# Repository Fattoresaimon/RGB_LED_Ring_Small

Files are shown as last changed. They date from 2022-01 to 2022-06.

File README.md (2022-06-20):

# RGB LED Ring Small
### This is the official repository of the RGB LED Ring Small!
### Available on my [DuPPa Store!](https://www.duppa.net/shop/rgb-led-ring-small/) or [Tindie](https://www.tindie.com/products/25812/)!

The RGB LED Ring Small is an accessory of the rotary encoder.
The shaft  of the encoder can be insert in the center hole of the board. It support both the normal rotary encoder and the RGB encoder.

There are 24 RGB LED disposed in a circle with a 30mm diameter. In total there are 72 LEDs.
Each single LED can be controller with 256 step, then each RGB LED are encoded with the 888 format.
The controller is the [ IS31FL3746](https://www.lumissil.com/assets/pdf/core/IS31FL3746A_DS.pdf)

In this repository you can find:
- [Schematic](/PDF/)
- [Gerbers](/Hardware/Gerber/)
- [BOM](/Hardware/BOM/)
- [Pick & Place](/Hardware/Pick%20Place/)
- [3D File](/Hardware/ExportSTEP/)

[Here you can find the Arduino library](https://github.com/Fattoresaimon/ArduinoDuPPaLib)

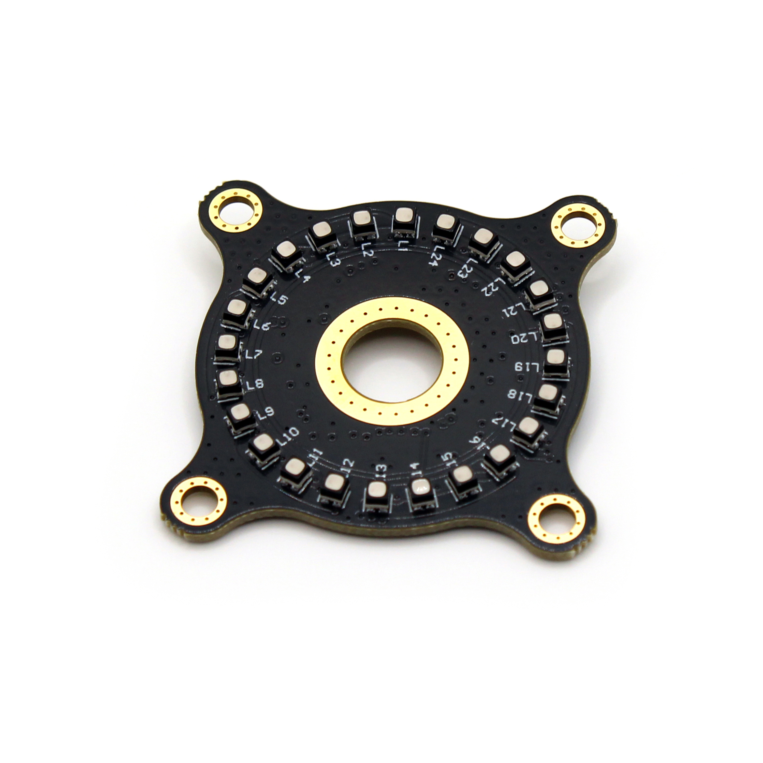
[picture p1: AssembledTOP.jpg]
Assembled


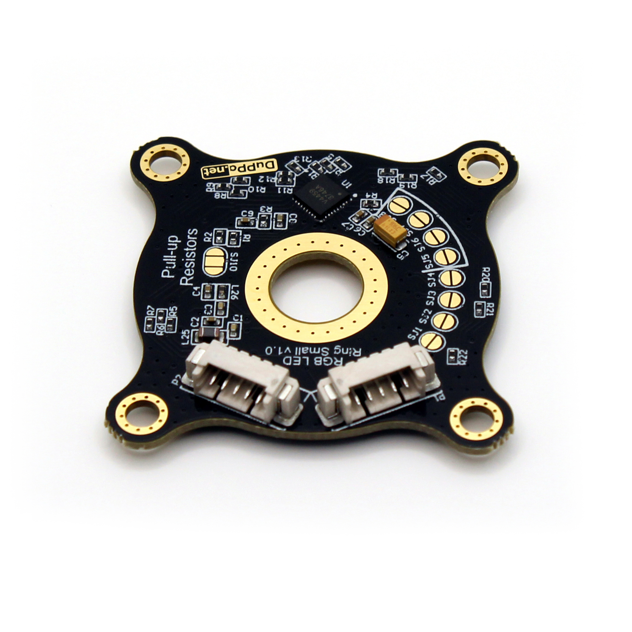
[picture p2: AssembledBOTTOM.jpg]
Bottom


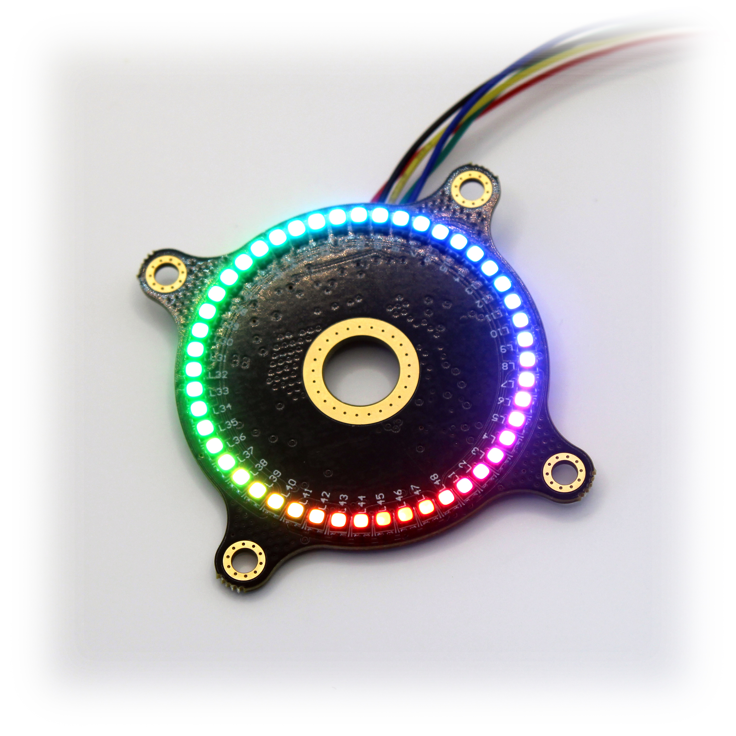
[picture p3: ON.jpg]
ON


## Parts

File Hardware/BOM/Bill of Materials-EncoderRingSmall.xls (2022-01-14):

Comment | Designator | Footprint | Quantity | Voltage | Value | PartNumber
C-EUC0402 | C1, C3 | C0402 | 2 | 16V | 10n | CL05B103KA5NNNC
C-EUC0402 | C2, C4, C7, C9 | C0402 | 4 | 16V | 100n | CL05B104KO5NNNC
Tantalum Case-A | C5 | SMC_A | 1 | 16V | 10u | CA45-A016K106T
C-EUC0402 | C6, C8 | C0402 | 2 | 16V | 470n | CL05A474KA5NNNC
RGB_2020_NH-Z1921RGBA-SG | L1, L2, L3, L4, L5, L6, L7, L8, L9, L10, L11, L12, L13, L14, L15, L16, L17, L18, L19, L20, L21, L22, L23, L24 | RGB_2121_NH-Z1921RGBA-SG | 24 |  |  | NH-Z1921RGBA-SG
600R@100MHz | L25 | L0805 | 1 |  |  | CBW201209U601T
600R@100MHz | L26 | L0402 | 1 |  |  | CBG100505U601T
Header 5HSMD | P1, P2 | MOLX-52361-0571-5_V | 2 |  |  | C22076
R-EU_R0402 | R1, R2, R3 | R0402 | 3 |  | 4k7 | 0402WGJ0472TCE
R-EU_R0402 | R4 | R0402 | 1 |  | 10k | RC-02W1002FT
R-EU_R0402 | R5, R8, R11, R14, R17, R20 | R0402 | 6 |  | 51r | RC0402JR-0751RL
R-EU_R0402 | R6, R7, R9, R10, R12, R13, R15, R16, R18, R19, R21, R22 | R0402 | 12 |  | 20r | RC0402JR-0720RL
IS31FL3746A | U1 | PQFN40P400X400X75_HS-33N | 1 |  |  | IS31FL3746A

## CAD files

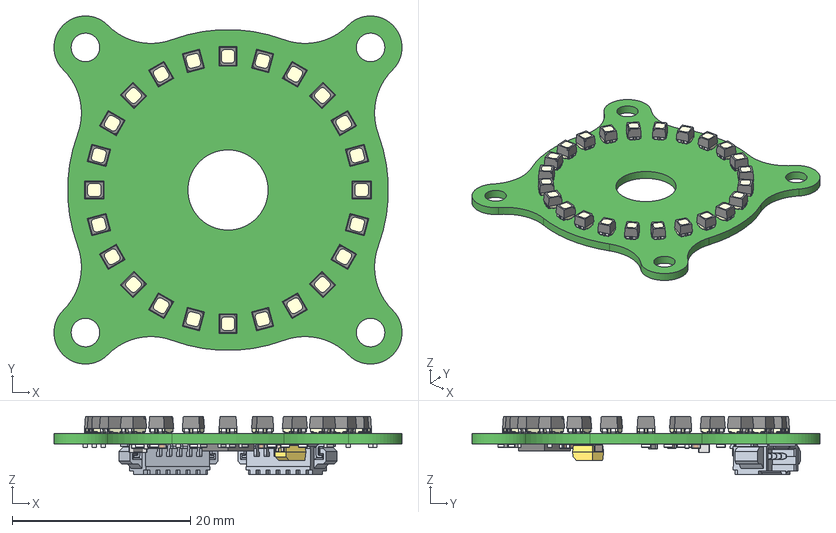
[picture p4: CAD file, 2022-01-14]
Hardware/ExportSTEP/EncoderRingSmall.step
39.1 x 39.1 x 6.51 mm
User_Library-R_0402 x 22
ASMB-KTF0-0A306--3DModel-STEP-56544 x 24
User_Library-V0402HD_K_X_F6rper_1
User_Library-V0402HD_Anschl_X_FCsse_1
User_Library-ind_0805
User_Library-Capacitor_0402 x 8
Open_CASCADE_STEP_translator_6.8_19.1
Open_CASCADE_STEP_translator_6.8_19.2.1
Thermal_Shape
Pin_Shape x 32

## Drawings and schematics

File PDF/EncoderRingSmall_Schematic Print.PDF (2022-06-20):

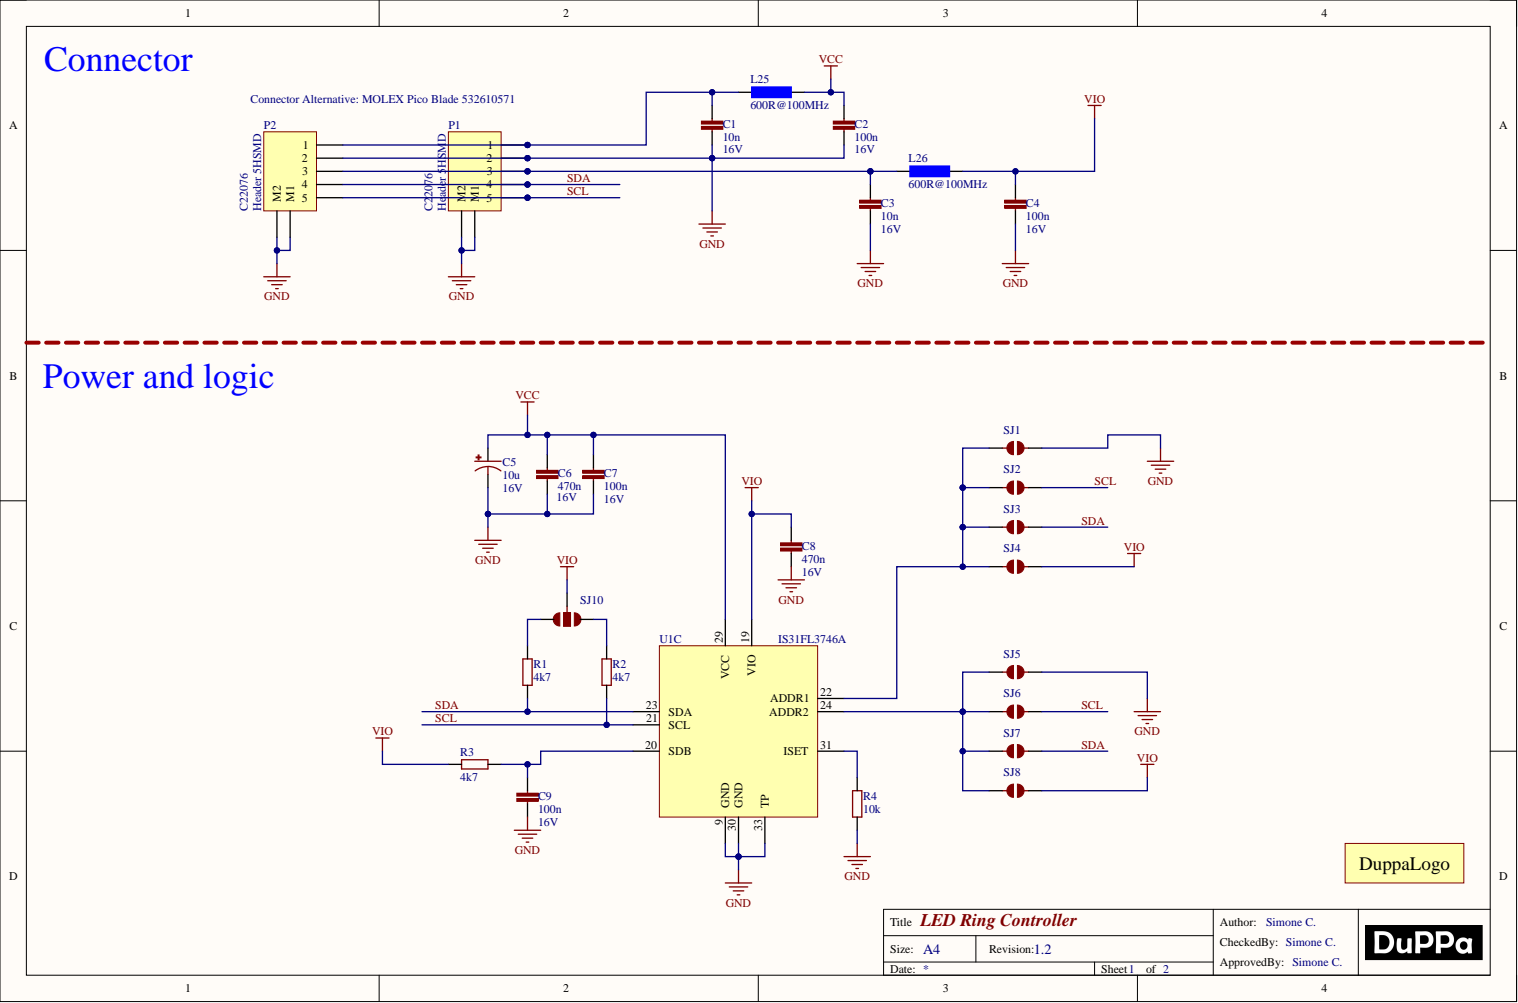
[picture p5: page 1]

Connector Alternative: MOLEX Pico Blade 532610571

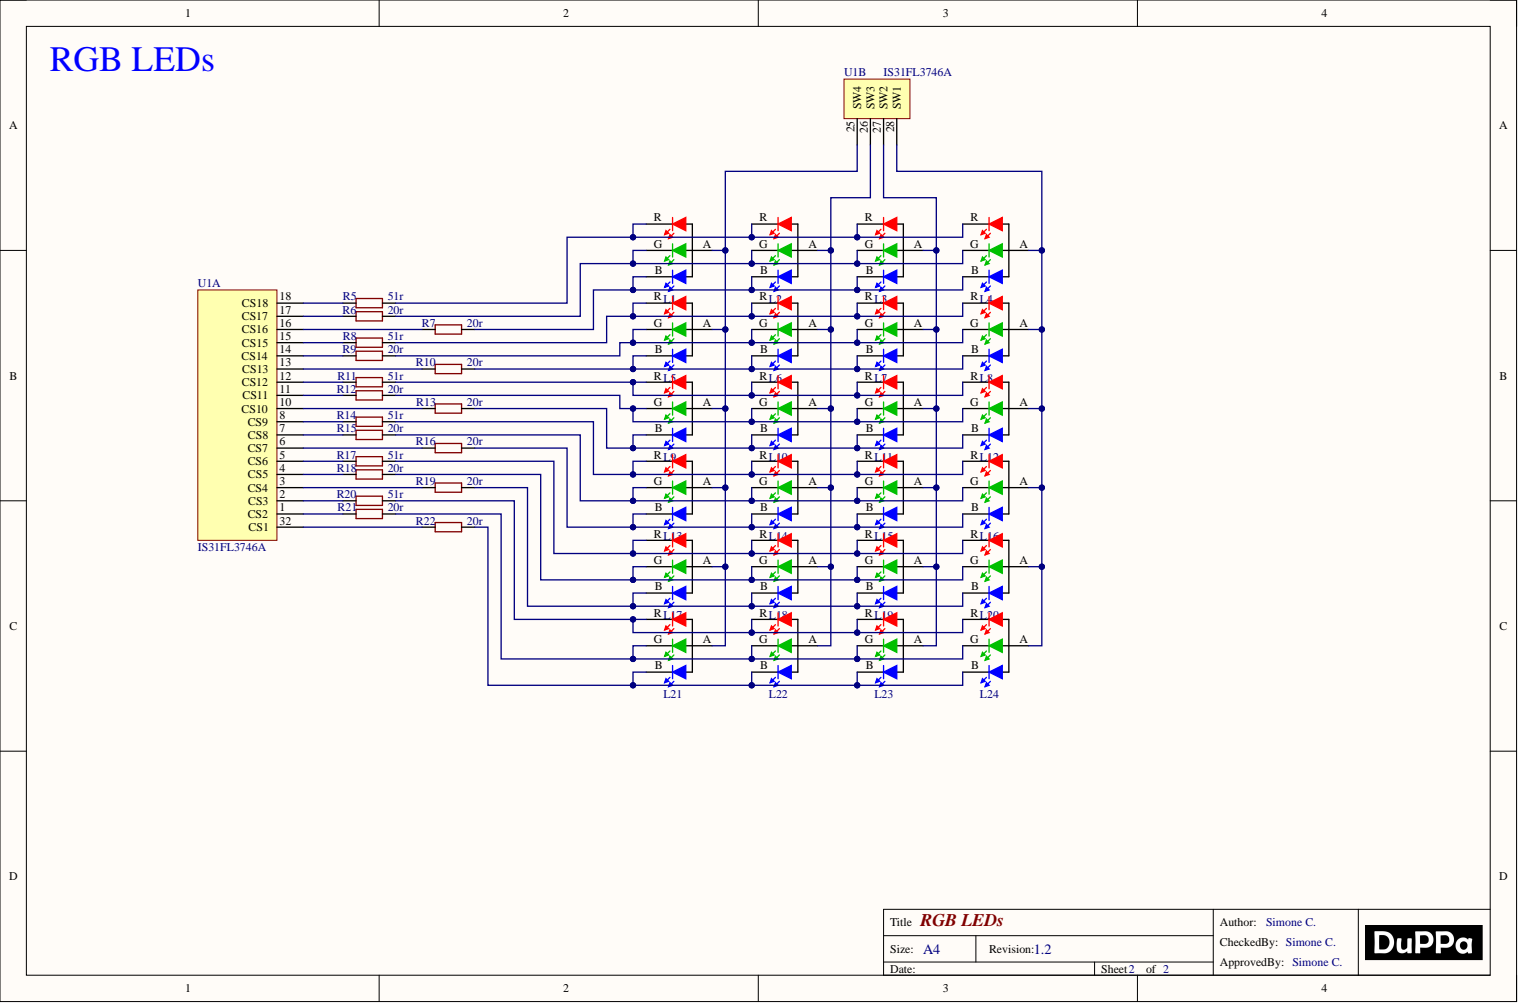
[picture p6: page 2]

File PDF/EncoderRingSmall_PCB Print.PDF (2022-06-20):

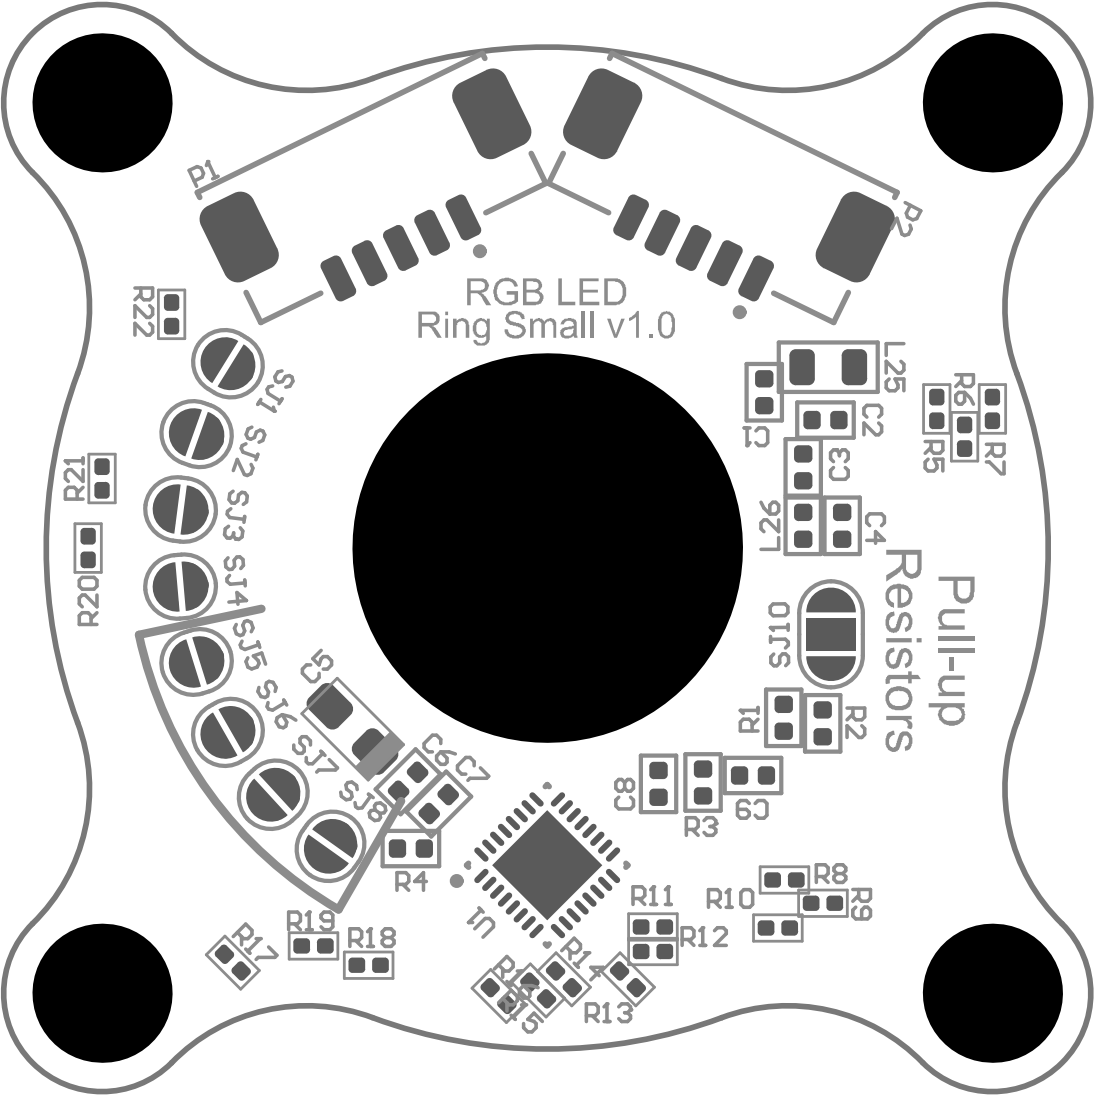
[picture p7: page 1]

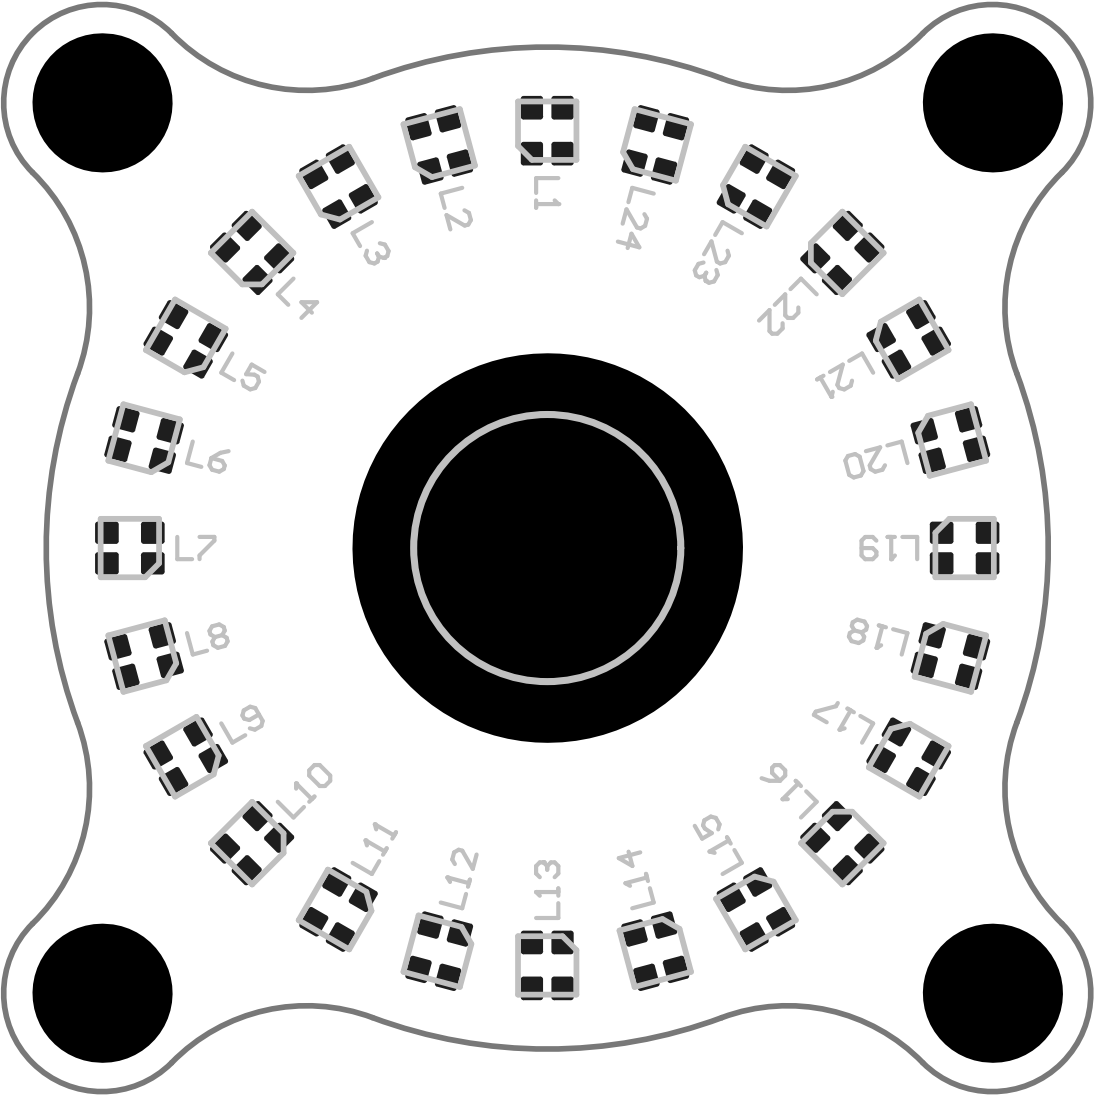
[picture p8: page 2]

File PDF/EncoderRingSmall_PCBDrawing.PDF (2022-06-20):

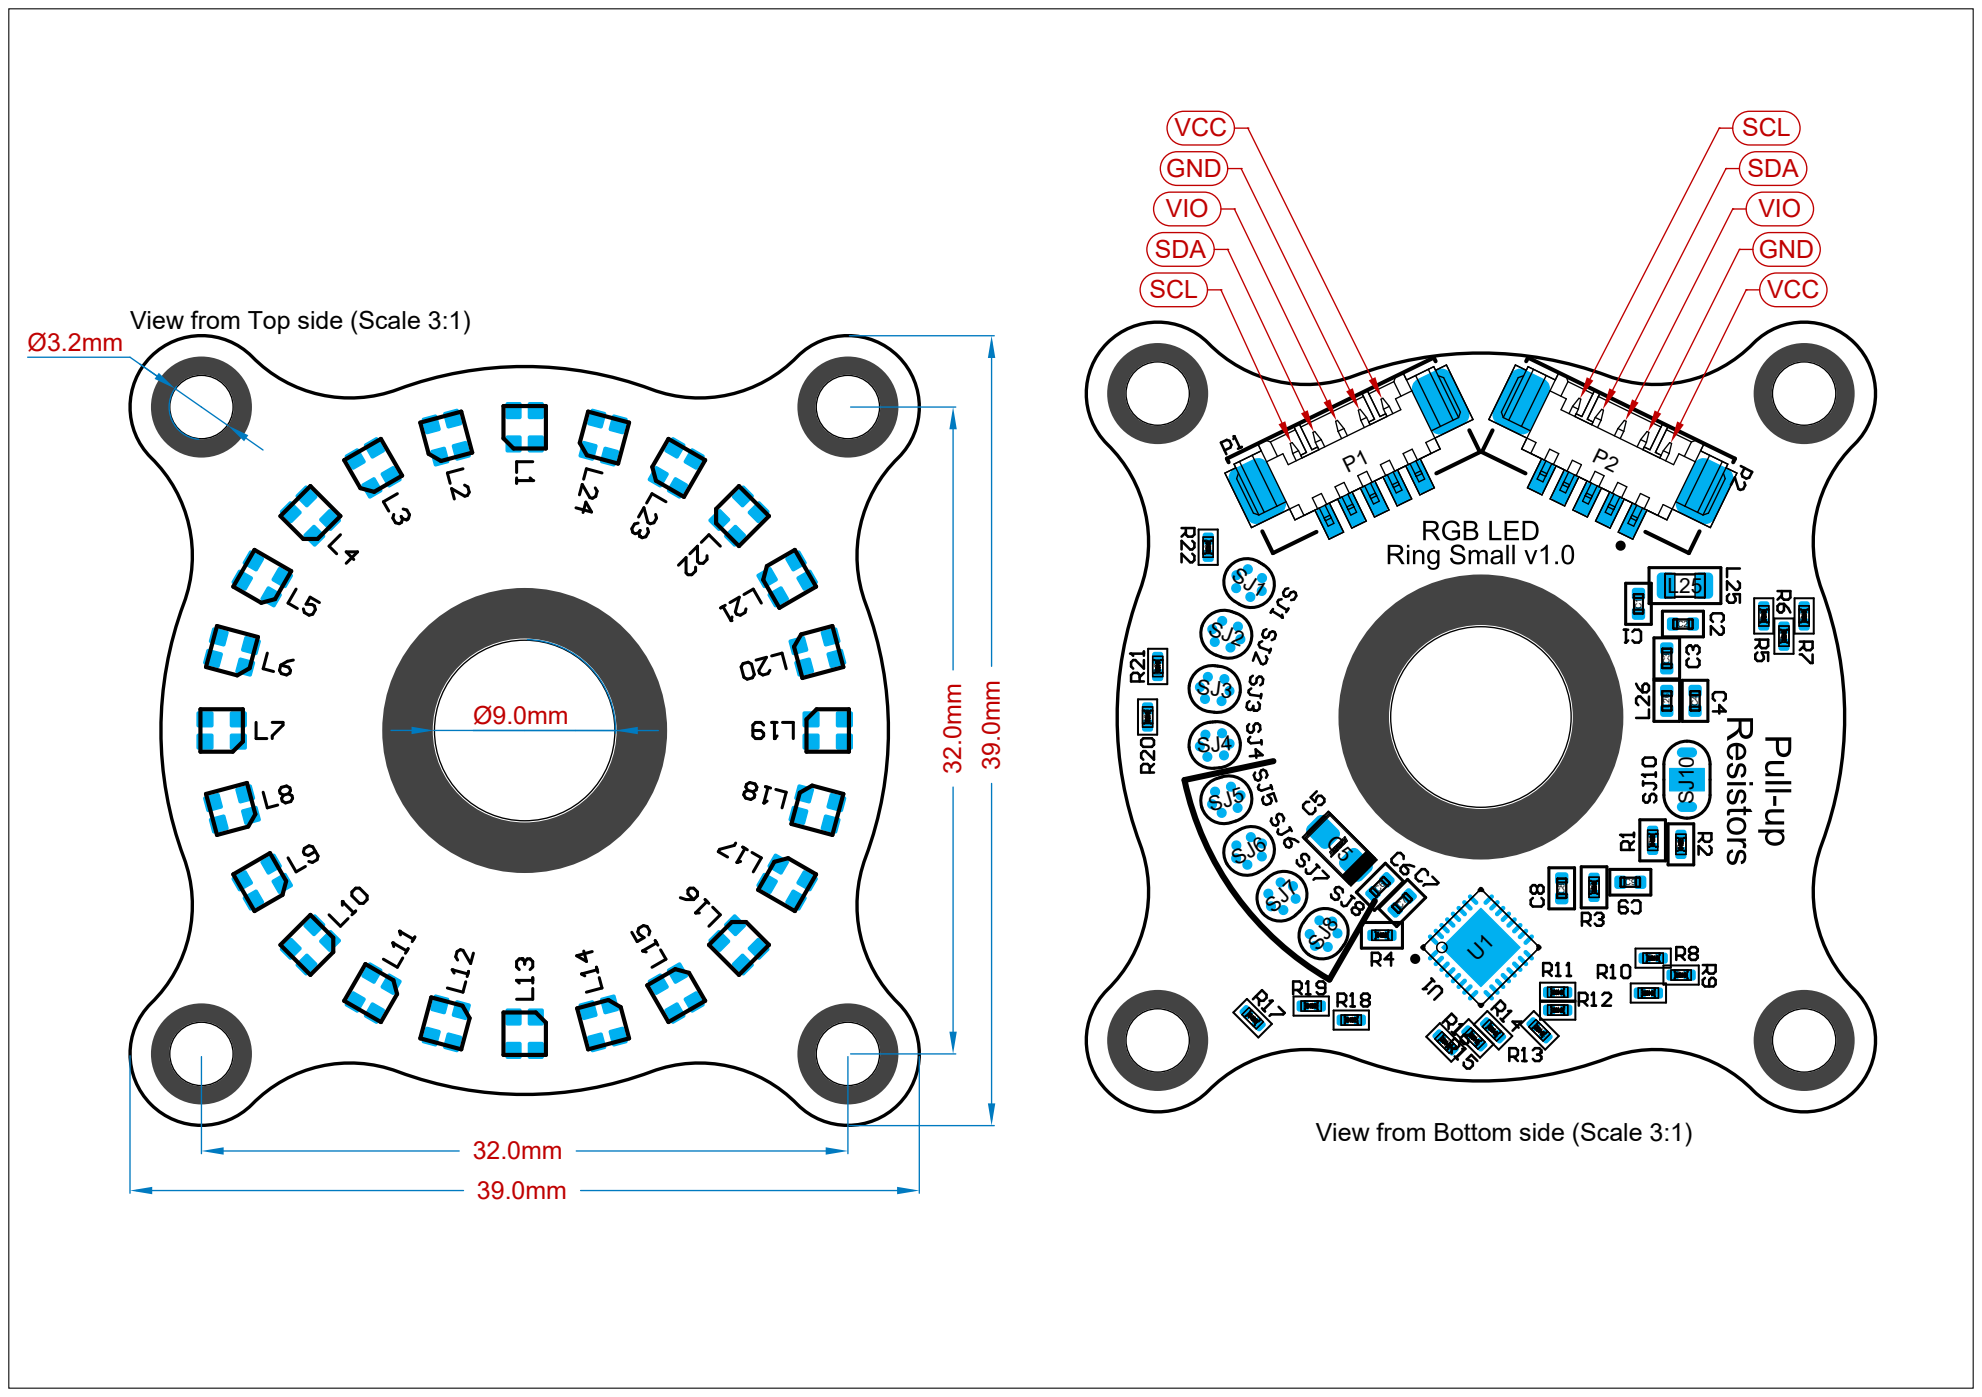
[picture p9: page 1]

View from Top side (Scale 3:1)

View from Bottom side (Scale 3:1)

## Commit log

2022-06-20 Added mechanical details
    [EncoderRingSmall.step]
2022-06-20 Revert "update"
    This reverts commit 66ed8751b3ca10eede1a0646de8e0fa5dfff4738.
    [Bill of Materials-EncoderRingSmall.xlsx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]
